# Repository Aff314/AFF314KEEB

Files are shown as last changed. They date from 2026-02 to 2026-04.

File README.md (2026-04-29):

# AFF314KEEB
A wireless 36-key low profile non split ergo keyboard.

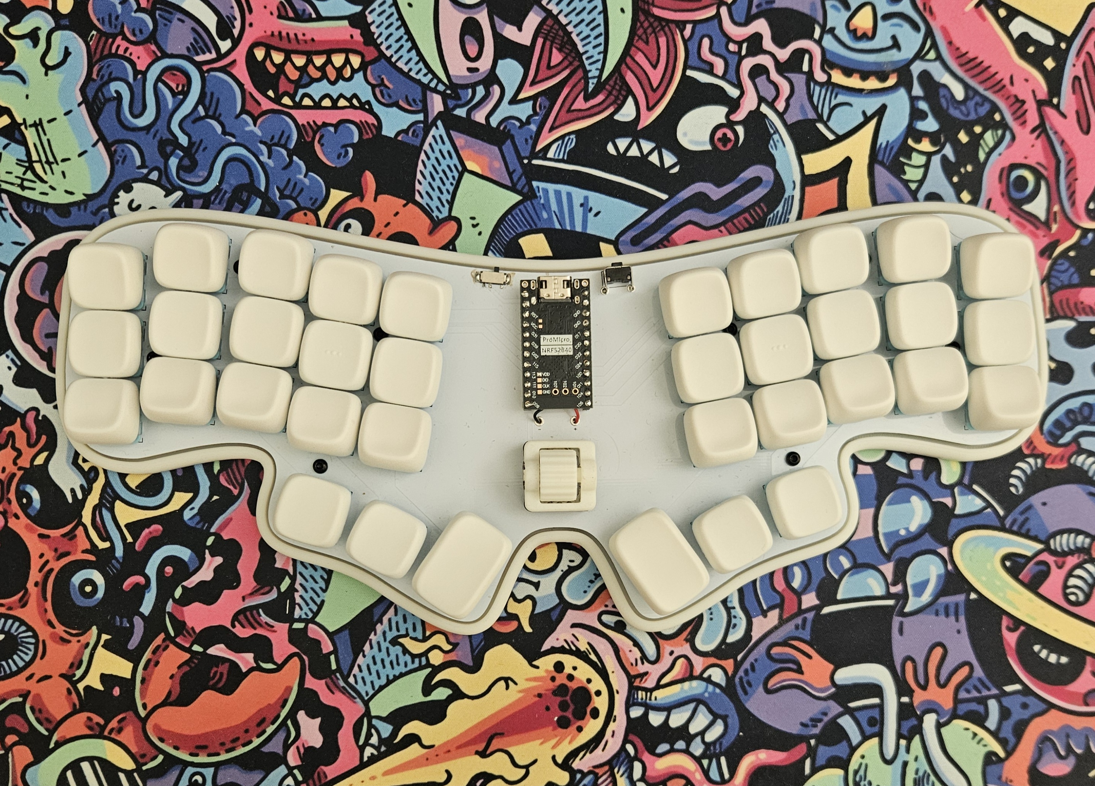
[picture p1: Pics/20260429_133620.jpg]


I started to make this project because I really like using 36-key boards and I've even built two and a handwired board which I designed myself, but never somthing with a PCB. I'm really intersted in those kinds of projects and really like the ones others made but I've never really did one of my own. In the process of designing the board I've learned a lot on how to use KiCad and for the first time I actually documented what I was doing.

I want to thank [Joe Scotto](https://github.com/joe-scotto) for the KiCad footprints and symbols and for the great tutorials on designing a keyboard case and on ZMK.

Additionally I want to thank [GEIST](https://github.com/GEIGEIGEIST) for the Kicad footprints.

And lastly I want to thank [Kumamuk](https://github.com/kumamuk-git) for the CKW12 which made having a roller encoder possible since the EVQWGD001 is way too expensive.

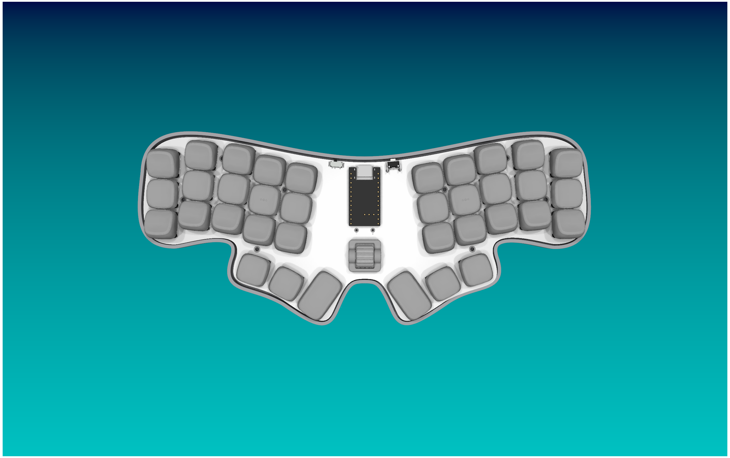
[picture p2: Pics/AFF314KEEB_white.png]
AFF314KEEB_front

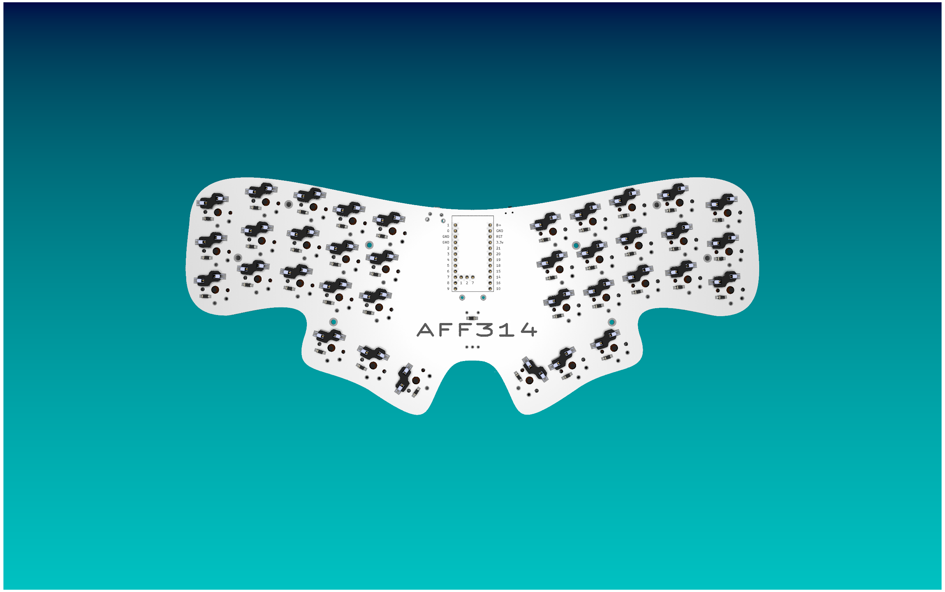
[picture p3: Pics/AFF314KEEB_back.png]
AFF314KEEB_back


## Instructions on buildung your own
If you want to build your own AFF314KEEB you should start to download the [Gerber file](PCB/Gerber.zip) and upload it to your prefered PCB manufacturing service and order it from there with the PCB from the CKW12 which you can find [here](https://github.com/kumamuk-git/CKW12).

You can find the rest of the parts in the [BOM](BOM.csv).

Once you have sourced all the parts you have to follow the [build guide](BUILDGUIDE.md).

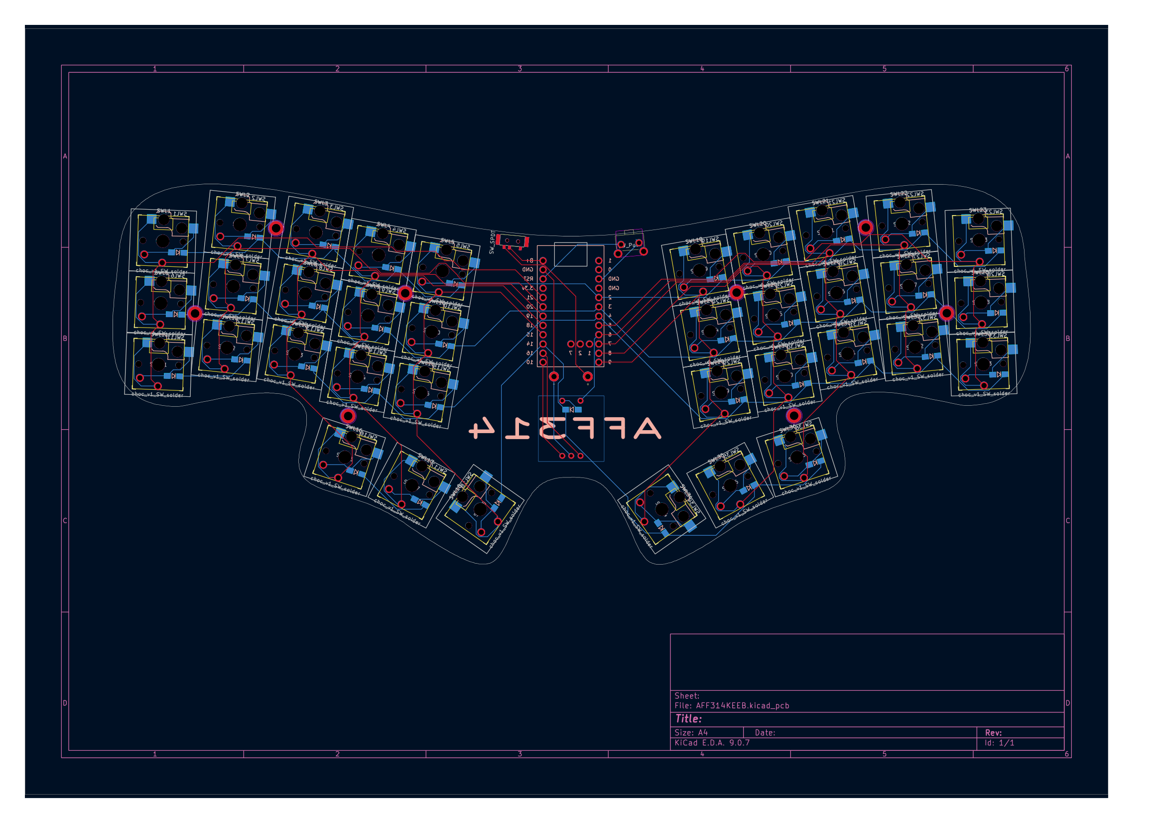
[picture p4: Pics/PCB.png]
PCB


## Partlist

Since I'm from Germany the prices were in EUR and I converted them to USD. Therefore they might not be one hundred percent accurate.

### Parts for the AFF314KEEB

| Item | Qty. | Total Price in USD | Link |
|---|---|---|---|
| NRF52840 NineNano v2 Clone | 1 | 3.77 | https://de.aliexpress.com/item/1005006271779544.html |
| Kailh Choc Hot-Swap Socket | 36 | 6.25 | https://de.aliexpress.com/item/1005008928238101.html |
| Kailh Choc V1 Switch | 36 | 34.24 | https://de.aliexpress.com/item/1005008701630340.html |
| 1N4148W SOD123 | 37 | 1.64 | https://de.aliexpress.com/item/1005006123061230.html |
| IC-Sockets 12pin | 2 | 1.76 | https://de.aliexpress.com/item/1005007476809536.html |
| 3.7 V 301230 | 1 | 4.10 | https://42keebs.eu/shop/parts/lithium-polymer-battery/?attribute_size=301230%20(110%20mAh) |
| SKHLLCA010 | 1 | 0.71 | https://keeb.supply/products/alps-reset-button?variant=e834d428-bed6-4fb3-b94a-90e8f8b87d9b |
| MillMax Pins 3320-0-00-15-00-00-03-0 (optional) | 24 | 3.78 | https://keeb.supply/products/millmax-pins?variant=29bd2804-2a61-4fea-bfe3-f96557a35bd5 |
| PCB | 1 | 14.31 | https://github.com/Aff314/AFF314KEEB/blob/main/PCB/Gerber.zip |
| Any Keycaps for Choc V1 | 36 |  | https://github.com/braindefender/KLP-Lame-Keycaps/tree/master/STEP/Choc%20Stem%20%2B%20Choc%20Size |
| 3D Printed Case | 1 |  | https://github.com/Aff314/AFF314KEEB/tree/main/Case |
| Heatseat insert M2x3x3.5 | 8 | 2.54 | https://de.aliexpress.com/item/1005010362011631.html |
| M2 screws 5mm | 8 | 1.70 | https://de.aliexpress.com/item/1005005070119421.html |

### Parts for the CKW12

| Item | Qty. | Total Price in USD | Link |
|---|---|---|---|
| SMD 3x6x2.5MM Tactile Button | 1 | 1.10 | https://de.aliexpress.com/item/1005008818216326.html |
| EC05E1220202 | 1 | 1.8 | https://de.aliexpress.com/item/1005007146553579.html |
| PCB | 1 | 2.40 | https://github.com/kumamuk-git/CKW12/tree/main/pcb/top |
| 3D Printed Housing | 1 |  | https://github.com/kumamuk-git/CKW12/blob/main/3dmodel/ckw12_housing.stp |
| 3D Printed Stem | 1 |  | https://github.com/kumamuk-git/CKW12/blob/main/3dmodel/ckw12_stem.stl |
| 3D Printed Wheel | 1 |  | https://github.com/kumamuk-git/CKW12/blob/main/3dmodel/ckw12_wheel_fix.stp |

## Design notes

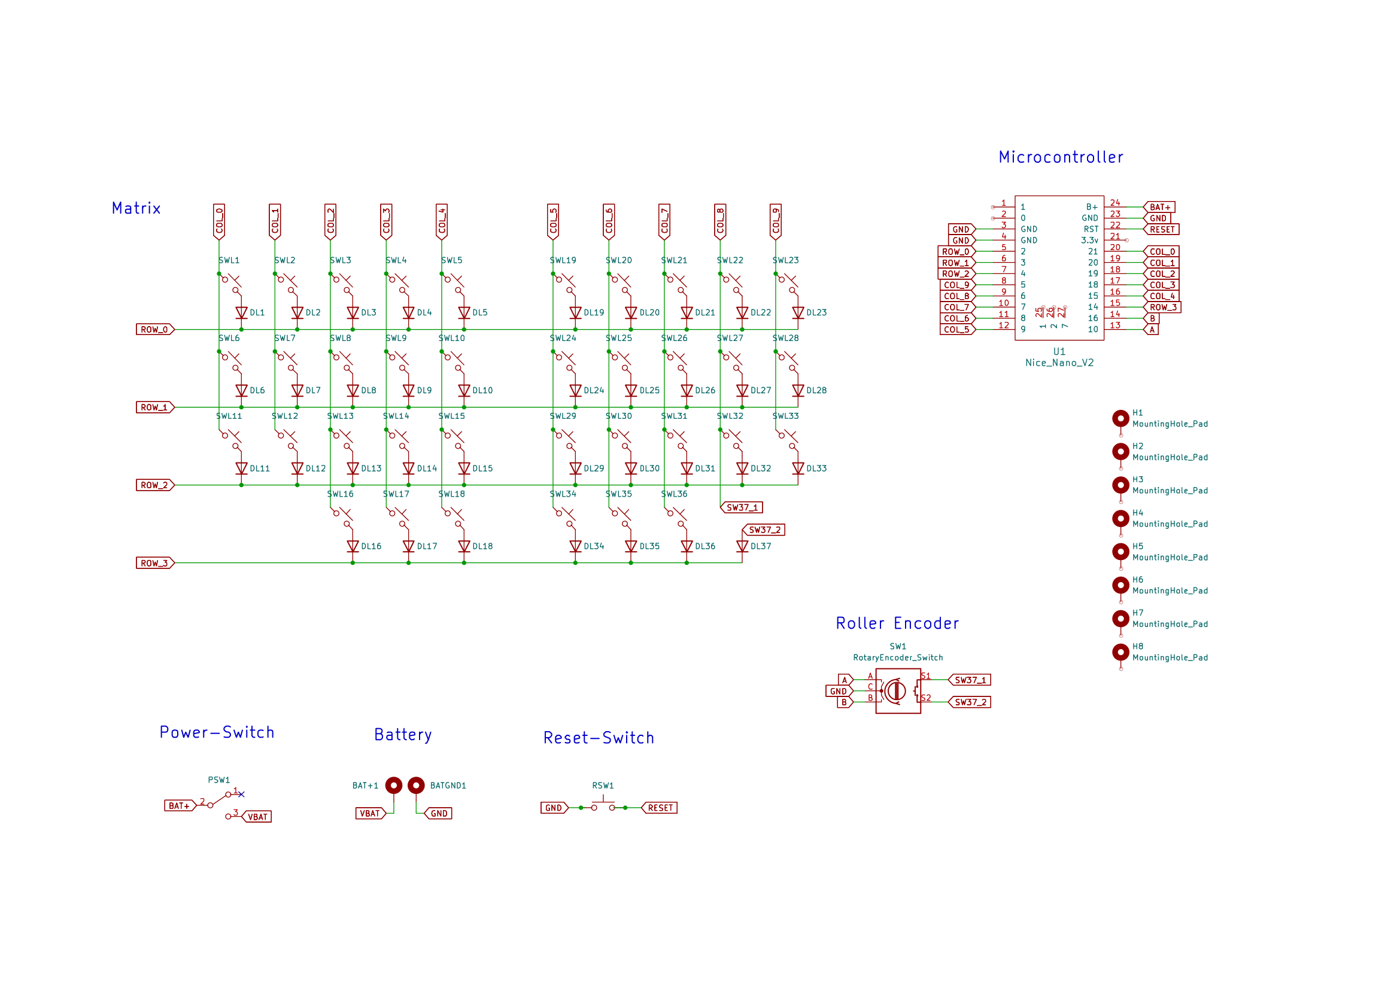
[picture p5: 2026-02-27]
Pics/Schematic.png

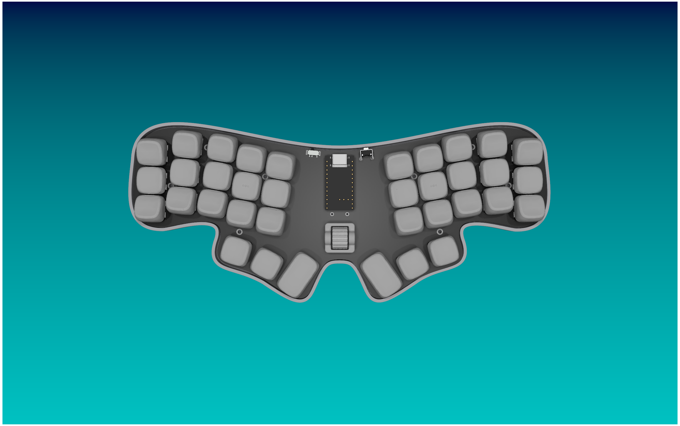
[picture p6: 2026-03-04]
Pics/AFF314KEEB_black.png

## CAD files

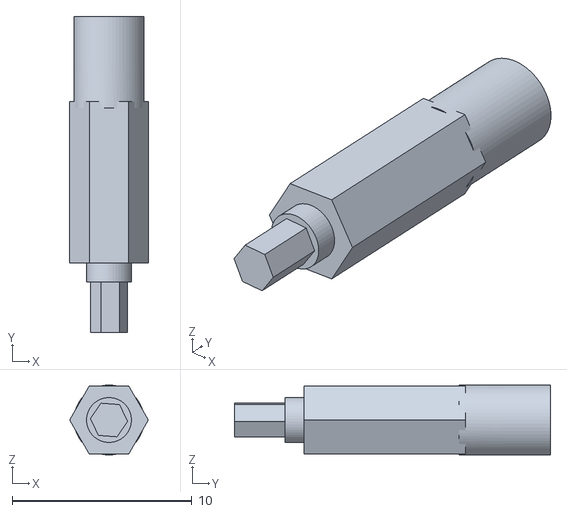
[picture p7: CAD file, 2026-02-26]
3Dmodel/ckw12_stem.stl
4.39 x 17.6 x 3.90

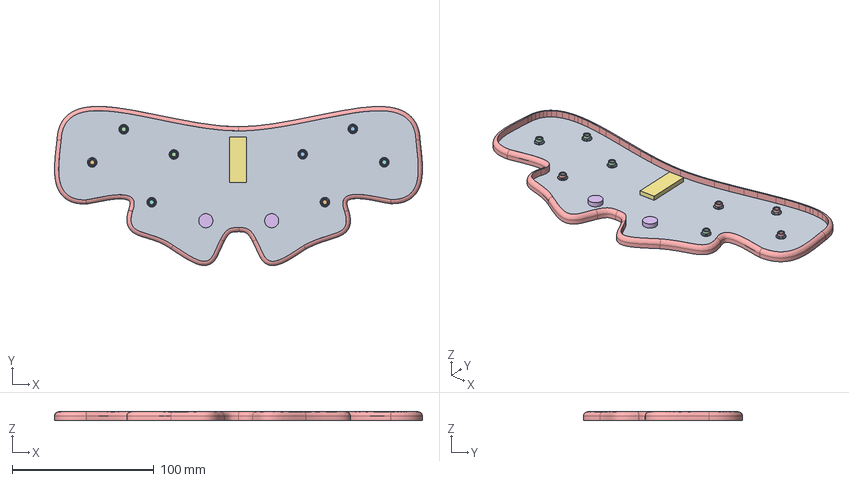
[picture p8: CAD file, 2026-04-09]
Case/AFF314KEEB_case.stp
259.7 x 112.3 x 6.00 mm

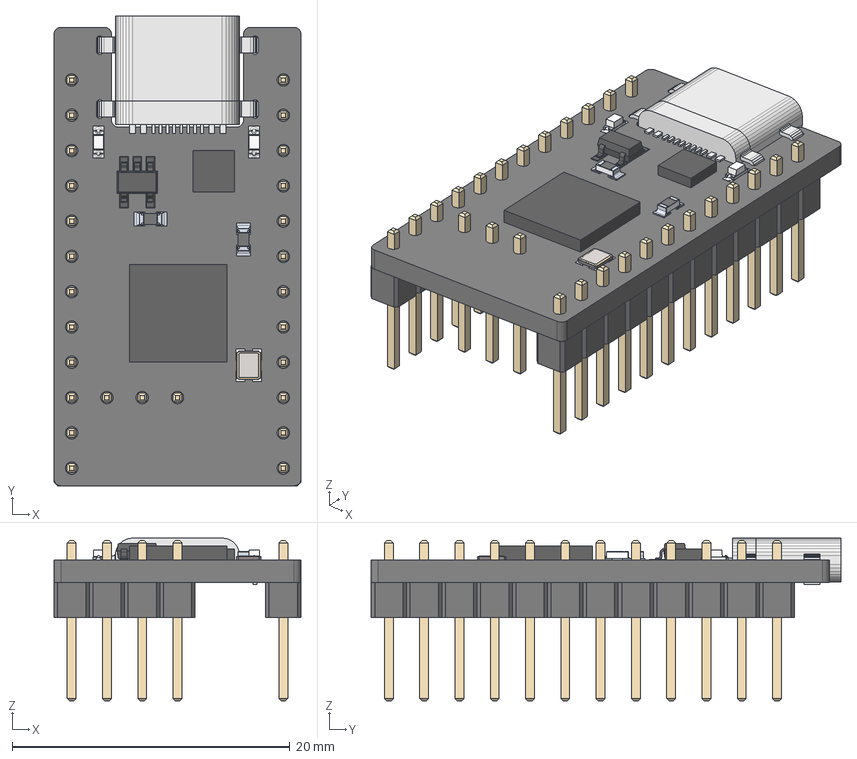
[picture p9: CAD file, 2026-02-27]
PCB/AFFE3D/Nice_Nano_V2.step
17.8 x 33.8 x 11.7 mm
PinHeader_1x12_P2.54mm_Vertical.step
User Library-TYPE-C-31-M-14.step
MICRO_603 resistor 102
MICRO_stackable header pin x 12
MICRO_stackable header 12
micro_crystal 5x3
MICRO_led
micro_MIC5219

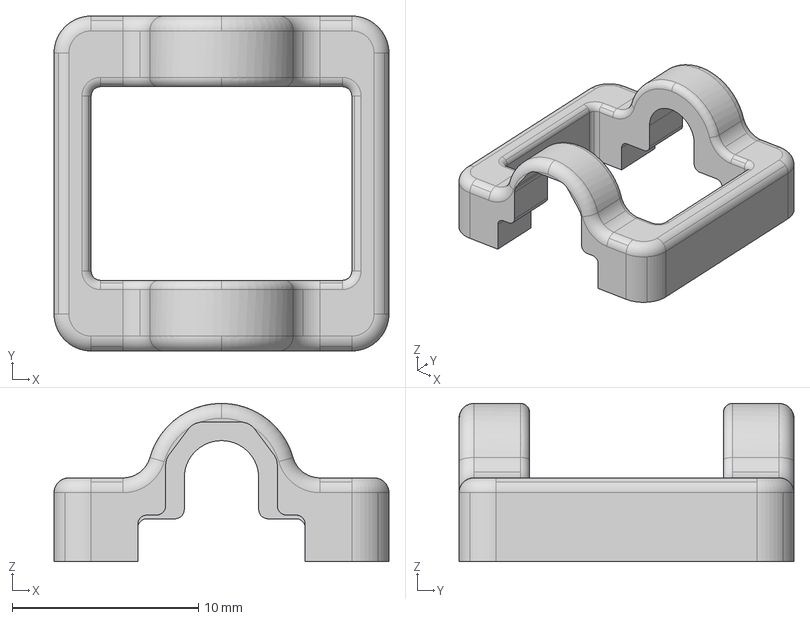
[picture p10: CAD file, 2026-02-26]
3Dmodel/ckw12_housing.stp
18.0 x 18.0 x 8.50 mm

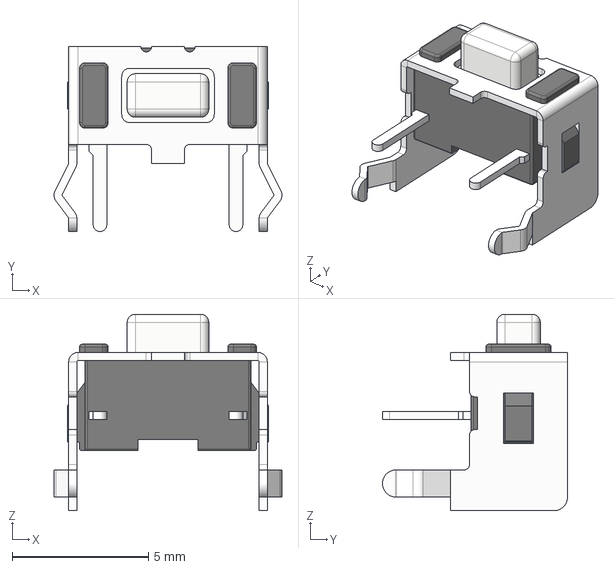
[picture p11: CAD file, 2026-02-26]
PCB/AFFE3D/SW_SKHLLC.step
8.38 x 6.80 x 7.22 mm

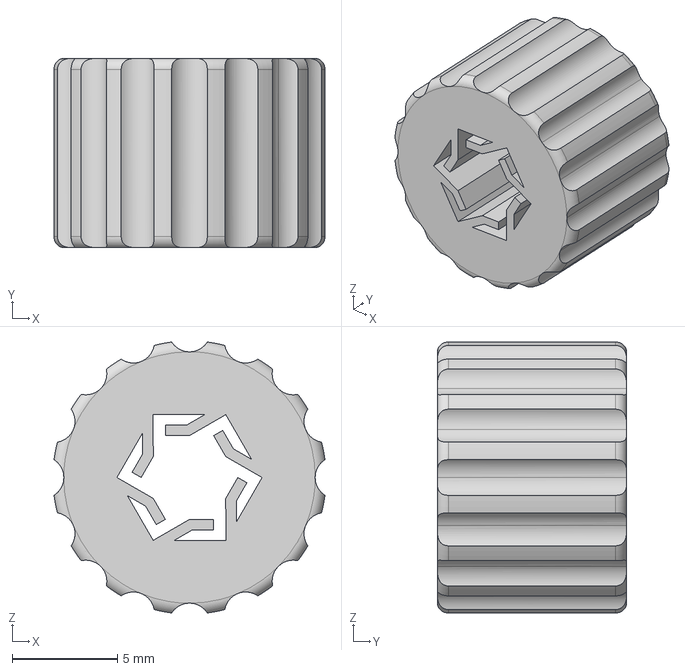
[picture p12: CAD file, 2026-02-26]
3Dmodel/ckw12_wheel_fix.stp
12.9 x 9.00 x 12.9 mm

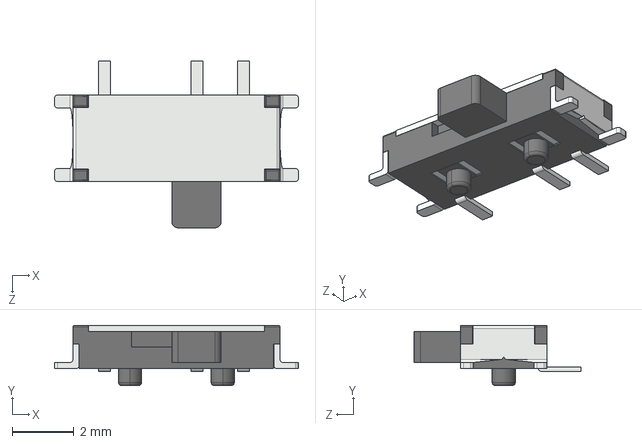
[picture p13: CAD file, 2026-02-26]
PCB/AFFE3D/MSK12C02.STEP
7.90 x 1.95 x 5.39 mm

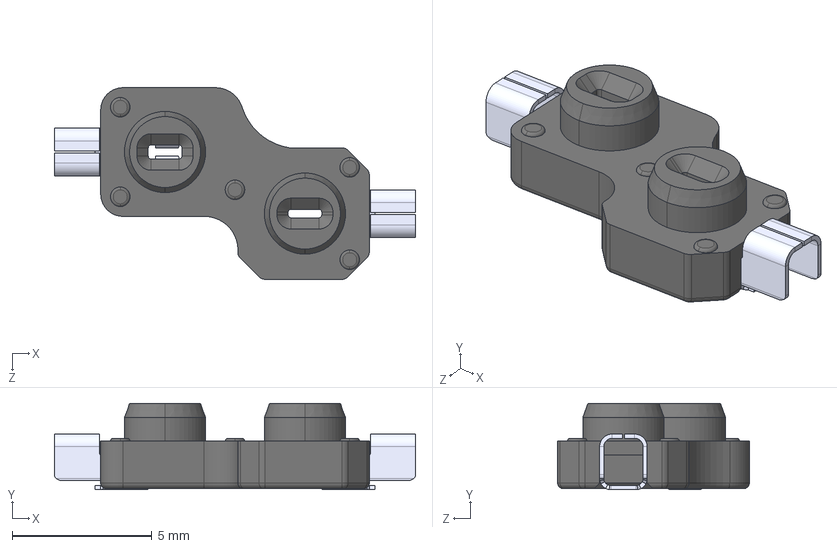
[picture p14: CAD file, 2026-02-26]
PCB/AFFE3D/Kailh_socket_PG1350_optional.STEP
12.9 x 3.09 x 6.85 mm
pin x 2
socket

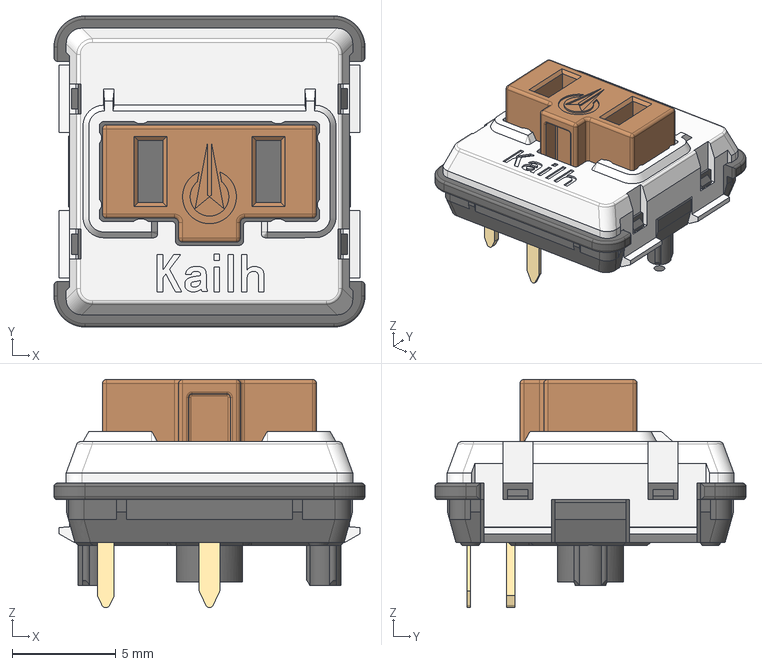
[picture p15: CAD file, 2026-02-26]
PCB/AFFE3D/Kailh_switch_PG1350_optional.step
15.0 x 15.0 x 11.0 mm

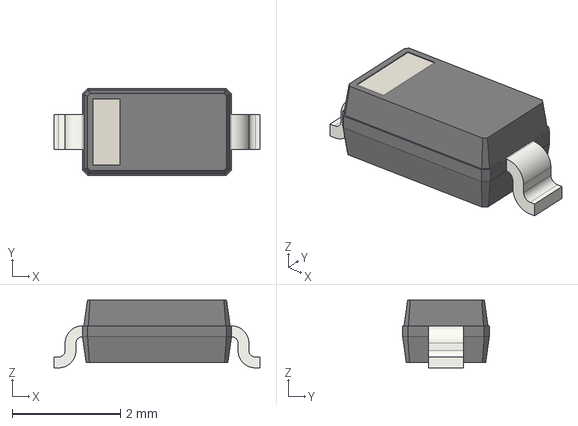
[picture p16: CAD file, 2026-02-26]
PCB/AFFE3D/D_SOD-123.step
3.80 x 1.60 x 1.25 mm

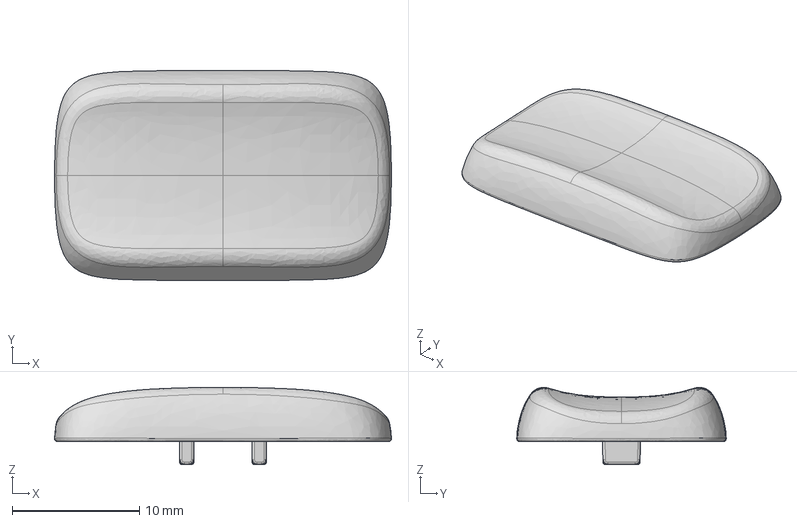
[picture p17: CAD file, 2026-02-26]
PCB/AFFE3D/Choc_Stem_Choc_Size_1.5U_Saddle_V.step
26.5 x 16.5 x 6.07 mm

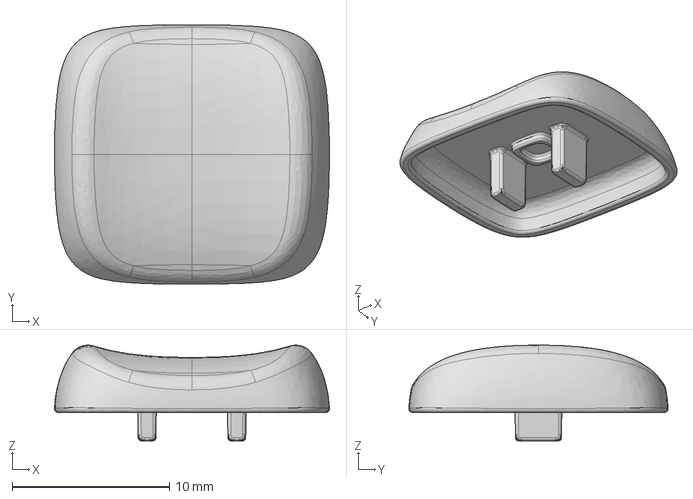
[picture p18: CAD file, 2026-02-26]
PCB/AFFE3D/Choc_Stem_Choc_Size_Saddle.step
17.5 x 16.5 x 6.08 mm

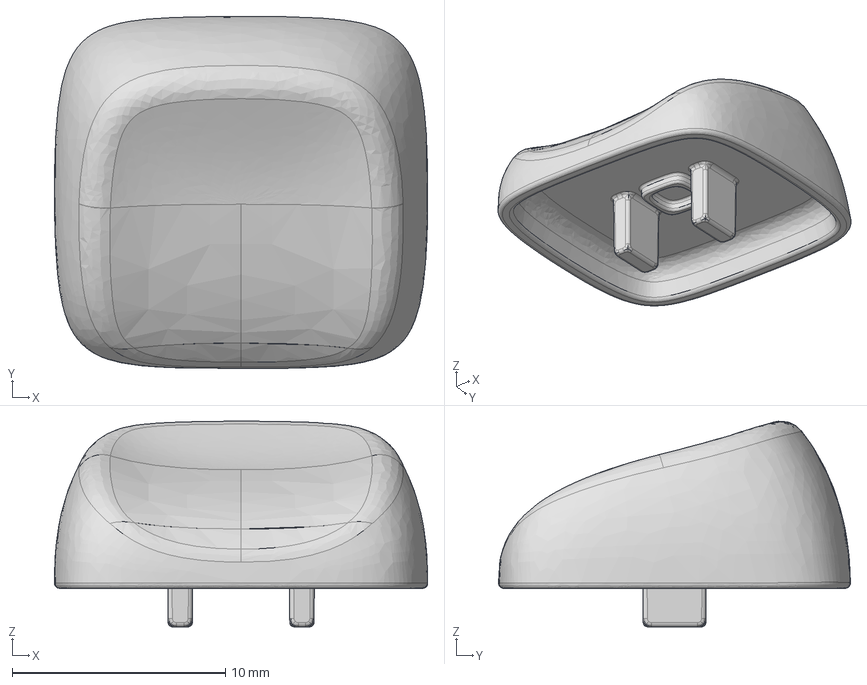
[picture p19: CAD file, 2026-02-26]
PCB/AFFE3D/Choc_Stem_Choc_Size_Saddle_Tilted.step
17.5 x 16.5 x 9.63 mm

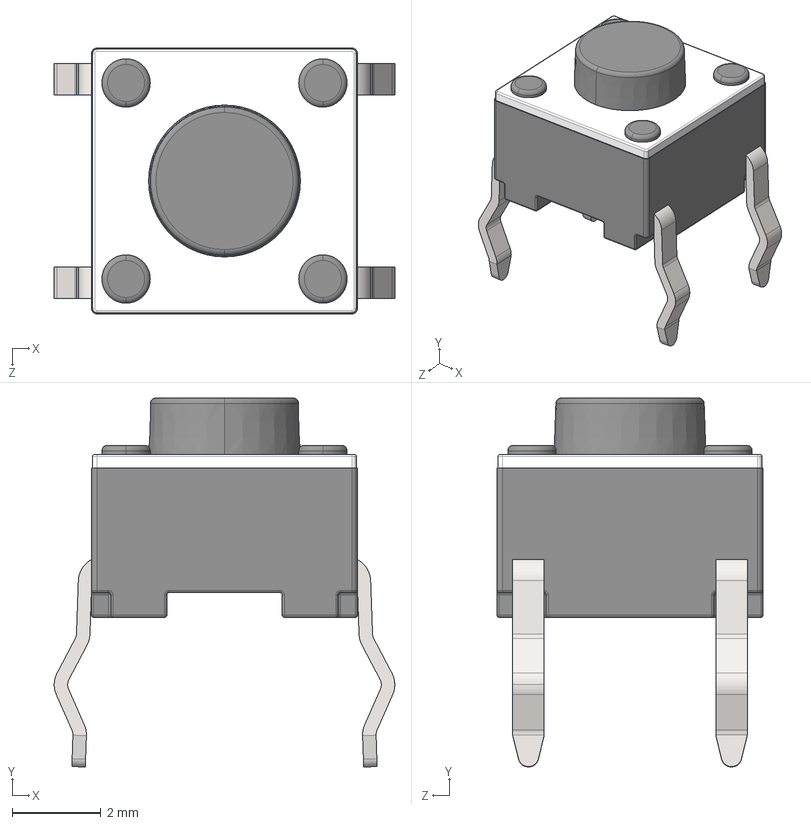
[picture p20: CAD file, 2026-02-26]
PCB/AFFE3D/SW_Push_1P1T_NO_6x6mm_H9.5mm.STEP
7.69 x 8.33 x 6.01 mm

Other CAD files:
PCB/AFFE3D/Choc_Stem_Choc_Size_Saddle_Homing.step
PCB/AFFE3D/Nice_Nano_V2_Flipped.step
Case/AFF314KEEB_case.stl

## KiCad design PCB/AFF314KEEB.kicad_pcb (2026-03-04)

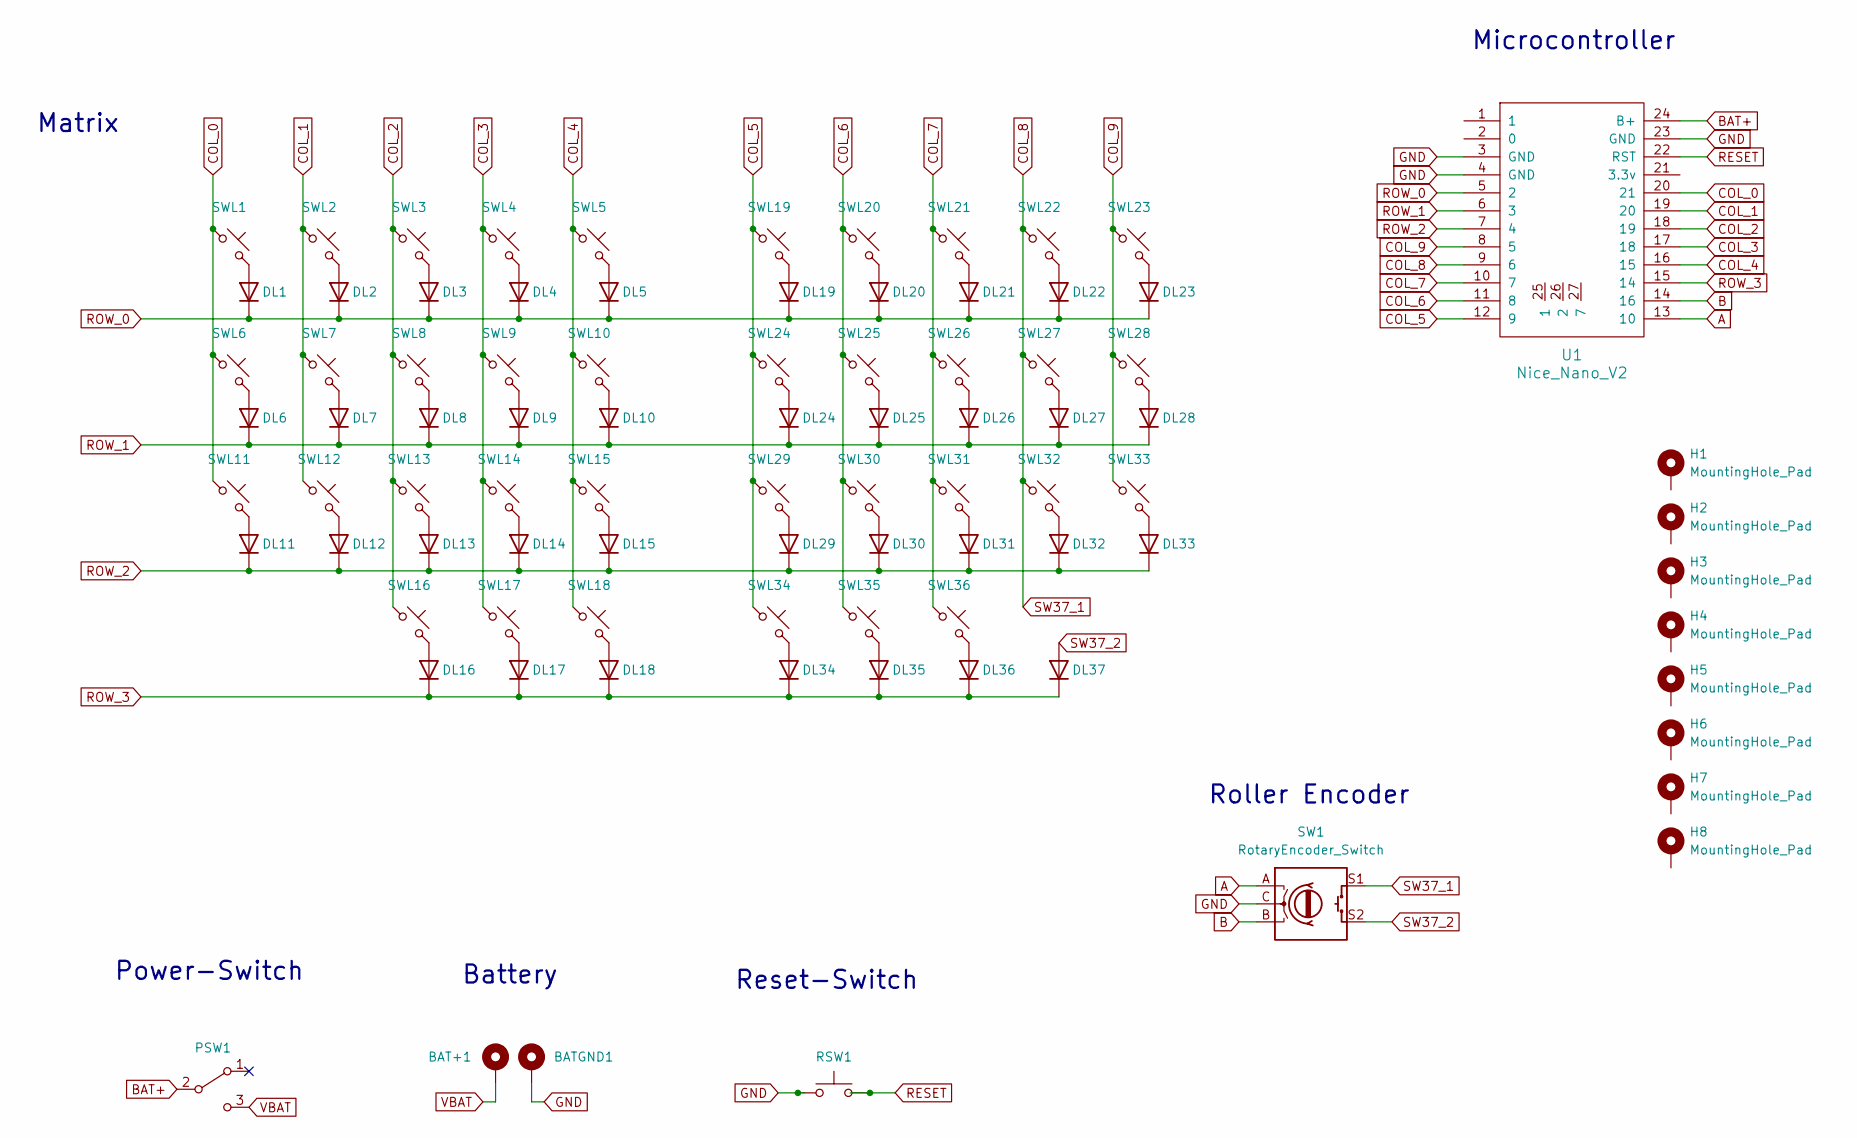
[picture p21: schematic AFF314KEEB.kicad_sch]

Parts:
BAT+1: +; BatteryPad
BATGND1: -; BatteryPad
DL1, DL2, DL3, DL4, DL5, DL6, DL7, DL8, DL9, DL10, DL11, DL12, DL13, DL14, DL15, DL16, DL17, DL18, DL19, DL20, DL21, DL22, DL23, DL24, DL25, DL26, DL27, DL28, DL29, DL30, DL31, DL32, DL33, DL34, DL35, DL36, DL37: D; Diode_SOD123
H1, H2, H3, H4, H5, H6, H7, H8: MountingHole_Pad; MountingHole_2.2mm_M2_DIN965_Pad_TopBottom
PSW1: SW_SPDT; MSK12C02
RSW1: SW_Push; SKHLLCA010
SW1: RotaryEncoder_Switch; CKW12
SWL1, SWL2, SWL3, SWL4, SWL5, SWL6, SWL7, SWL8, SWL9, SWL10, SWL11, SWL12, SWL13, SWL14, SWL15, SWL16, SWL17, SWL18, SWL19, SWL20, SWL21, SWL22, SWL23, SWL24, SWL25, SWL26, SWL27, SWL28, SWL29, SWL30, SWL31, SWL32, SWL33, SWL34, SWL35, SWL36: choc_v1_SW_solder; Kailh_socket_PG1350_optional
U1: Nice_Nano_V2; Nice_Nano_V2_Flipped

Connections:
A: SW1.A, U1.13 (10)
B: SW1.B, U1.14 (16)
BAT+: PSW1.2 (B), U1.24 (B+)
COL_0: SWL1.1, SWL6.1, SWL11.1, U1.20 (21)
COL_1: SWL2.1, SWL7.1, SWL12.1, U1.19 (20)
COL_2: SWL3.1, SWL8.1, SWL13.1, SWL16.1, U1.18 (19)
COL_3: SWL4.1, SWL9.1, SWL14.1, SWL17.1, U1.17 (18)
COL_4: SWL5.1, SWL10.1, SWL15.1, SWL18.1, U1.16 (15)
COL_5: SWL19.1, SWL24.1, SWL29.1, SWL34.1, U1.12 (9)
COL_6: SWL20.1, SWL25.1, SWL30.1, SWL35.1, U1.11 (8)
COL_7: SWL21.1, SWL26.1, SWL31.1, SWL36.1, U1.10 (7)
COL_8: SW1.S1, SWL22.1, SWL27.1, SWL32.1, U1.9 (6)
COL_9: SWL23.1, SWL28.1, SWL33.1, U1.8 (5)
GND: BATGND1.1, RSW1.1, SW1.C, U1.3 (GND), U1.4 (GND), U1.23 (GND)
unnamed: DL1.2 (A), SWL1.2
unnamed: DL2.2 (A), SWL2.2
unnamed: DL3.2 (A), SWL3.2
unnamed: DL4.2 (A), SWL4.2
unnamed: DL5.2 (A), SWL5.2
unnamed: DL6.2 (A), SWL6.2
unnamed: DL7.2 (A), SWL7.2
unnamed: DL8.2 (A), SWL8.2
unnamed: DL9.2 (A), SWL9.2
unnamed: DL10.2 (A), SWL10.2
unnamed: DL11.2 (A), SWL11.2
unnamed: DL12.2 (A), SWL12.2
unnamed: DL13.2 (A), SWL13.2
unnamed: DL14.2 (A), SWL14.2
unnamed: DL15.2 (A), SWL15.2
unnamed: DL16.2 (A), SWL16.2
unnamed: DL17.2 (A), SWL17.2
unnamed: DL18.2 (A), SWL18.2
unnamed: DL19.2 (A), SWL19.2
unnamed: DL20.2 (A), SWL20.2
unnamed: DL21.2 (A), SWL21.2
unnamed: DL22.2 (A), SWL22.2
unnamed: DL23.2 (A), SWL23.2
unnamed: DL24.2 (A), SWL24.2
unnamed: DL25.2 (A), SWL25.2
unnamed: DL26.2 (A), SWL26.2
unnamed: DL27.2 (A), SWL27.2
unnamed: DL28.2 (A), SWL28.2
unnamed: DL29.2 (A), SWL29.2
unnamed: DL30.2 (A), SWL30.2
unnamed: DL31.2 (A), SWL31.2
unnamed: DL32.2 (A), SWL32.2
unnamed: DL33.2 (A), SWL33.2
unnamed: DL34.2 (A), SWL34.2
unnamed: DL35.2 (A), SWL35.2
unnamed: DL36.2 (A), SWL36.2
RESET: RSW1.2, U1.22 (RST)
ROW_0: DL1.1 (K), DL2.1 (K), DL3.1 (K), DL4.1 (K), DL5.1 (K), DL19.1 (K), DL20.1 (K), DL21.1 (K), DL22.1 (K), DL23.1 (K), U1.5 (2)
ROW_1: DL6.1 (K), DL7.1 (K), DL8.1 (K), DL9.1 (K), DL10.1 (K), DL24.1 (K), DL25.1 (K), DL26.1 (K), DL27.1 (K), DL28.1 (K), U1.6 (3)
ROW_2: DL11.1 (K), DL12.1 (K), DL13.1 (K), DL14.1 (K), DL15.1 (K), DL29.1 (K), DL30.1 (K), DL31.1 (K), DL32.1 (K), DL33.1 (K), U1.7 (4)
ROW_3: DL16.1 (K), DL17.1 (K), DL18.1 (K), DL34.1 (K), DL35.1 (K), DL36.1 (K), DL37.1 (K), U1.15 (14)
SW37_2: DL37.2 (A), SW1.S2
VBAT: BAT+1.1, PSW1.3 (C)

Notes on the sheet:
Battery
Matrix
Reset-Switch
Microcontroller
Roller Encoder
Power-Switch

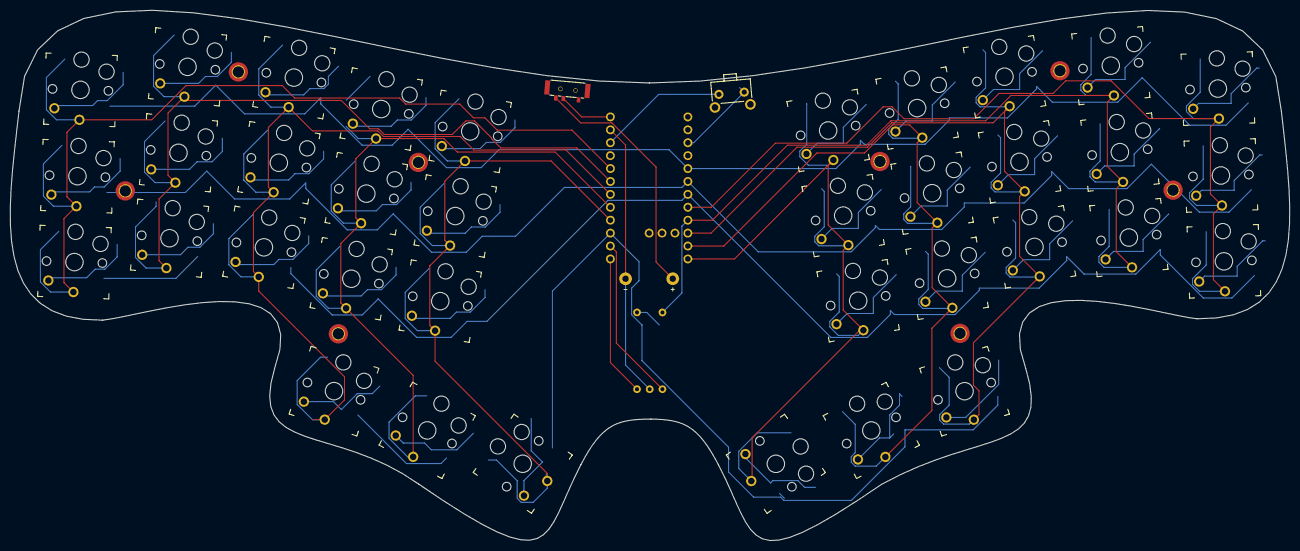
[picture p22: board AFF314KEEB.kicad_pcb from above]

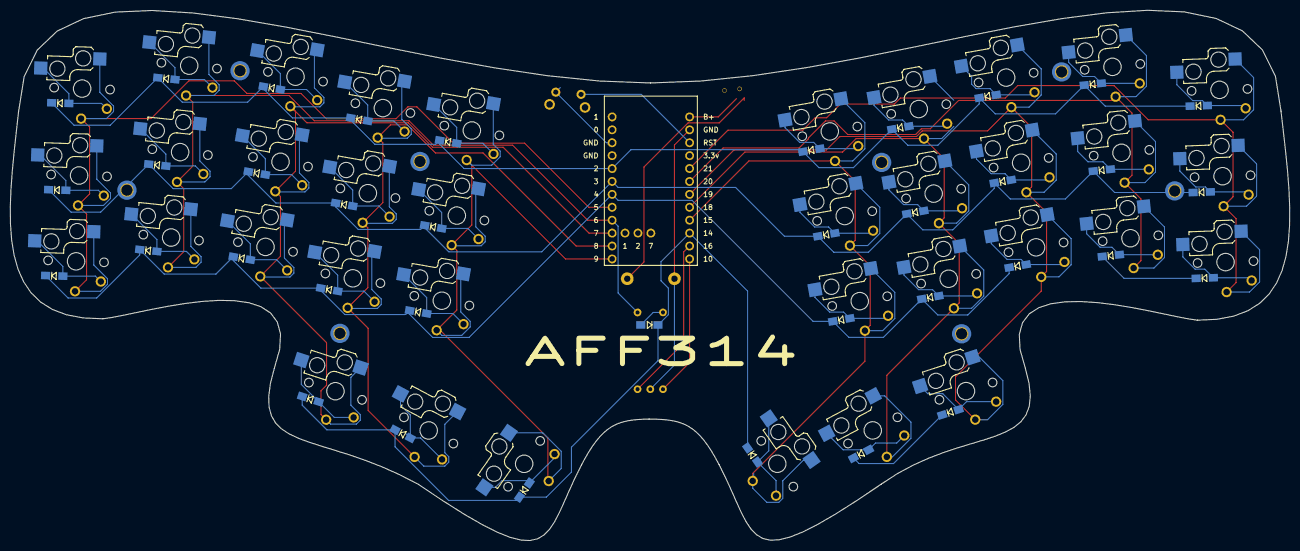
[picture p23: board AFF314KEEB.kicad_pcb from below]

Board: 2 copper layers, 251.7 x 104.3 mm, 87 parts (37 on the bottom side), 57 nets.

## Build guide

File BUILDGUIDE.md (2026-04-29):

# Bulid guide

## Building the board

### Soldering the diodes
The diodes are really small and can be a bit tricky to solder but it's actually not that difficult.
The most important thing is that you solder them on in the right direction. You can find a line on the PCB and on the diode. They have to match.

As far as soldering goes you first have to put a bit of solder on one pad and place the correct diode leg on there, while heating it up with your soldering iron. 
Then you have to just solder on the other leg and if you need to you can now improve the solder joint of the first leg.

### Soldering the hotswap sockets
Same as the diodes you have to solder on one side first and then the other.

If you build it without hotswap sockets you have to insert all switches and solder the oins directly.

### Soldering the MCU
At first you have to solder the pins to the MCU. I use MillMax pins which you can find in the BOM since they're more rigid, but you you can alternatively use through hole diode legs.
If you have a breadboard laying around use that and if you don't just try to make it as straight as possible. 

First cut the ic-sockets to 12 pin lenght if you've ordered the longer. Then push them into the breadboard, lay the MCU on it and push in the pins. Then you have to solder all the pins.

Now take out the sockets and place them on the PCB with the MCU attached and solder them from the bottom.

### Soldering the reset switch
Insert the reset switch and solder every thing on.

### Soldering the power switch solder 
You need to place the switch in it's position and first solder on the big pads and then the small ones. 

### Soldering the battery
If your battery has a connector you have to cut it off. The wires have to be short enough so the battery fits properly under MCU.

Then you have to place the battery under the MCU. Turn off the power switch and solder the red wire to the + pad and the black wire to the - pad.

## Flashing the firmware
First you have to download the [uf2 file](Firmware/AFF314KEEB-nice_nano_v2-zmk.uf2) or you could build the firmware on your own if for example you wanted to change the keymap or anything else. 
If you want to build the firmware yourself [here](Firmware/ZMK_config) are the ZMK config files which you can modify and compile. If you don't know hot that works you can watch a [tutorial](https://www.youtube.com/watch?v=O_urj-rF3bQ).

Once you've got your uf2 file you have to put your MCU in bootloder mode by connecting it to your pc and double pressing the reset-button.
Once it shows up as a drive (probably named NICENANO) you have to copy the file to the MCU. It should now disconnect and then the firmware is succesfully flashed.

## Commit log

2026-02-26 Adding files
    [AFF314KEEB-B_Cu.gbr, AFF314KEEB-B_Mask.gbr, AFF314KEEB-B_Paste.gbr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]
2026-02-27 Add BOM and update case
    [BOM.csv]
2026-02-27 Add PCB image to README
2026-02-27 Add encoder to firmware and update step file
2026-02-27 Revise BUILDGUIDE.md with initial instructions
    Updated the build guide with sections on building the board and flashing firmware.
2026-02-27 Add image of AFF314KEEB with case
    Added an image of the keyboard to the README.
2026-02-28 update
    Updated BOM.csv to include header row.
    [BOM.csv]
2026-02-28 Add Heatseat insert M2x3x3.5 to parts list
2026-02-28 Update BOM.csv with new items and adjustments
    Added a new item and updated quantities and prices in the BOM.
    [BOM.csv]
2026-02-28 small update
    Added missing header and rearranged item entries.
    [BOM.csv]
2026-02-28 Add 3.7 V 301230 battery to components list
2026-03-04 Small PCB tweak
    [AFF314KEEB-B_Cu.gbr, AFF314KEEB-B_Mask.gbr, AFF314KEEB-B_Paste.gbr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]
2026-03-07 Replace case files
    [AFF314KEEB_case.stl, AFF314KEEB_case.stp]
2026-03-07 Update case files
    [AFF314KEEB_case.stl, AFF314KEEB_case.stp]
2026-04-09 case and firmware changed
    [AFF314KEEB_case.stl, AFF314KEEB_case.stp]
